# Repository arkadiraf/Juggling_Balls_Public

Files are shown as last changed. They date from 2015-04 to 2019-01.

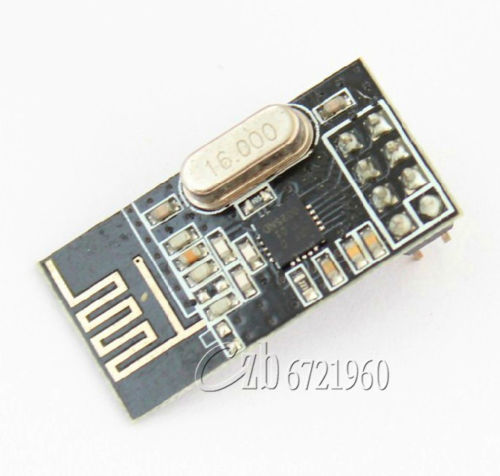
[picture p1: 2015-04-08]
Images/NRF24.JPG

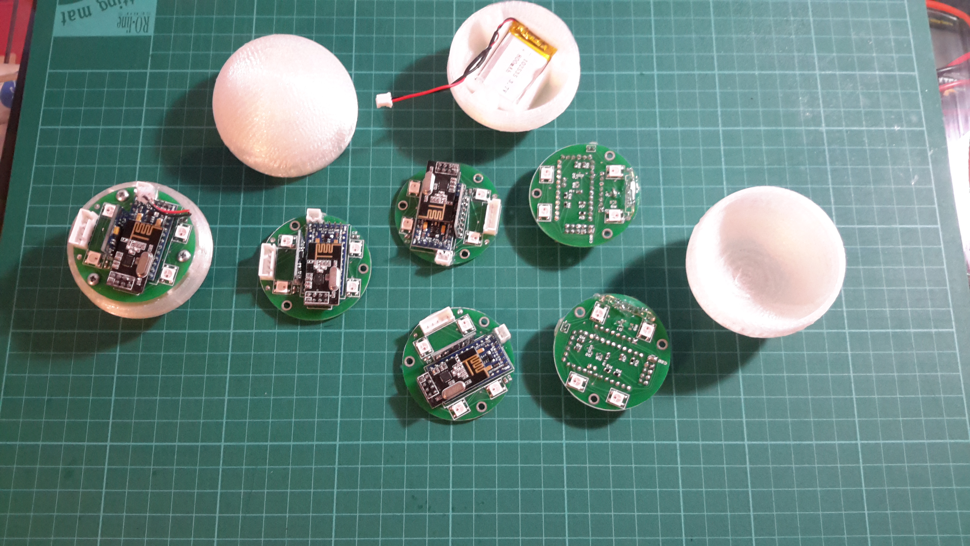
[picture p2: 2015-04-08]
Images/20150408_191757.jpg

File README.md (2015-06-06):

# Juggling_Balls_Public
Smart Juggling Balls is a project of mine which consists of 3 basic modules: 
arduino pro mini (compatible) MPU 6050 and nrf24
and a bunch of LEDS of course :)
The files I publish include the PCB manufacturing Gerber files
STL files for the casing (ment for 3d printing)
and some code I wrote.
The idea is to have colorful and happy juggling balls which can change lightning based on the sensor readings 
and remote maniputations communicating via nrf24.

<br /><span xmlns:dct="http://purl.org/dc/terms/" property="dct:title">Juggling_Balls</span> is licensed under a <a rel="license" href="http://creativecommons.org/licenses/by-nc-sa/4.0/">Creative Commons Attribution-NonCommercial-ShareAlike 4.0 International License</a>.

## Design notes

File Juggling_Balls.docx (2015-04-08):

Smart Juggling Balls: https://youtu.be/MuF92wXwjuk

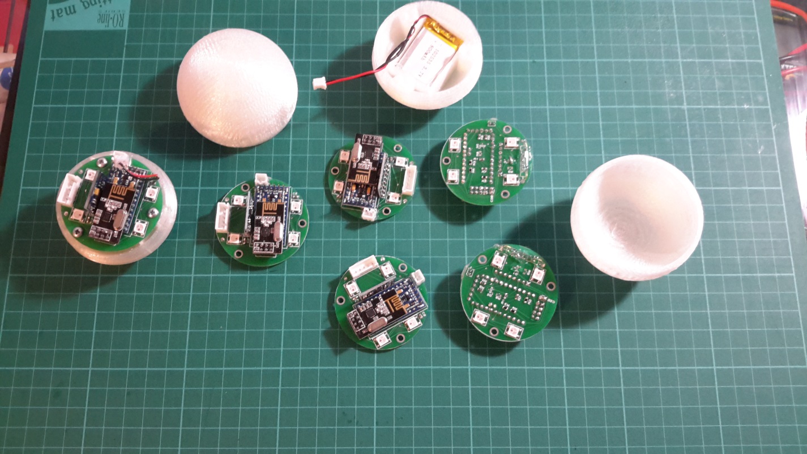
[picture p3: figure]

This is my version for smart juggling balls, the files I share include PCB Circuit manufacture files (Gerber)

STL models for the casing, and codes (currently Test code).

It is possible to assemble the juggling balls using a prototype PCB such as: https://www.sparkfun.com/products/8810 my first iterations were based on the same prototype board and later the PCB was design based on the physical dimensions of the board.

The circuit itself can be ordered from SeeeStudio http://www.seeedstudio.com/service/index.php?r=pcb

Just upload the Attached zip in Circuit→JB_Gerber.zip and order a standard 2 layer pcb. (Schematics are available in Circuit→Juggling_Balls.PDF

STL files for the casing are available in STL→Juggling_Maker_Faire

There are 2 versions one is a bit thicker.

All parts and links are available in Juggling_Balls_Bom.xlsx

Some notes on assembling:

Currently the power circuit (Transistor and mosfet) weren`t tested out,I use a wire to short the mosfet and use the connected pin (D8) as a magnet detector through the reed switch.

In one of the batches the holes for the arduino board came a bit tight so I was required to drill wider and then solder the pins for the arduino model from both sides of the pcb.

The Nrf model pins are needed to be cut a bit and the plastics removed so the NRF model will sit flat on the 2x4 header.

The circuit is design for the arduino compatible models available on ebay, such that the pinout for the FTDI is as in the image: (alternatively it is possible to use a different arduino version without soldering the FTDI headers to the pcb board, in that case the 5 pin connector will not be connected to the board DTR).

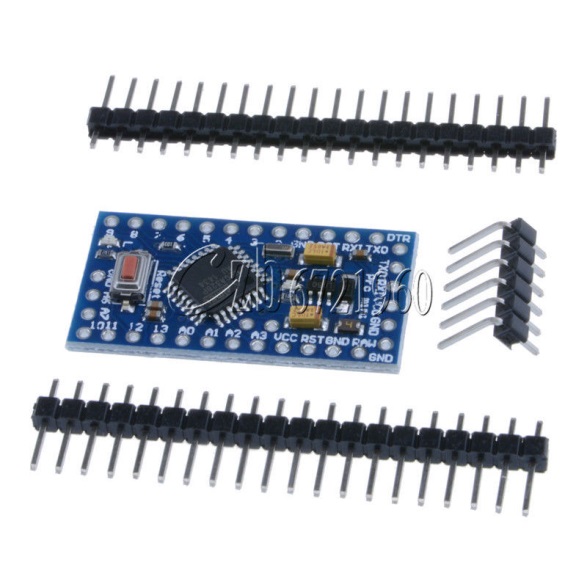
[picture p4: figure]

The direction of the SMD RGB LEDS such that the ‘cut’ corner of the LED first in the small Square drawn on the PCB.

All Resistors and capacitors aren`t Solid science, feel free to make variations, I myself solder a 1 uF capacitor instead the 47 uF and use 10kOhm resistors instead the 47kOhm

Note the correct direction for the Pin headers

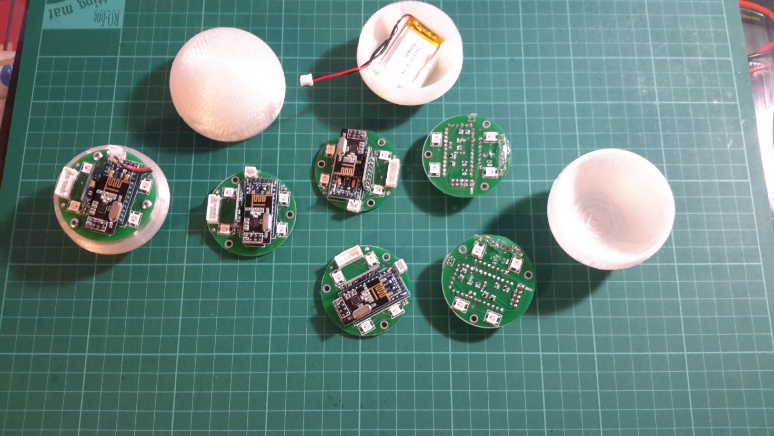
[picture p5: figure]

Enjoy.

Thanks to Eugene: http://techno-mind.ru/ for helping with the initial PCB design for manufacturing.

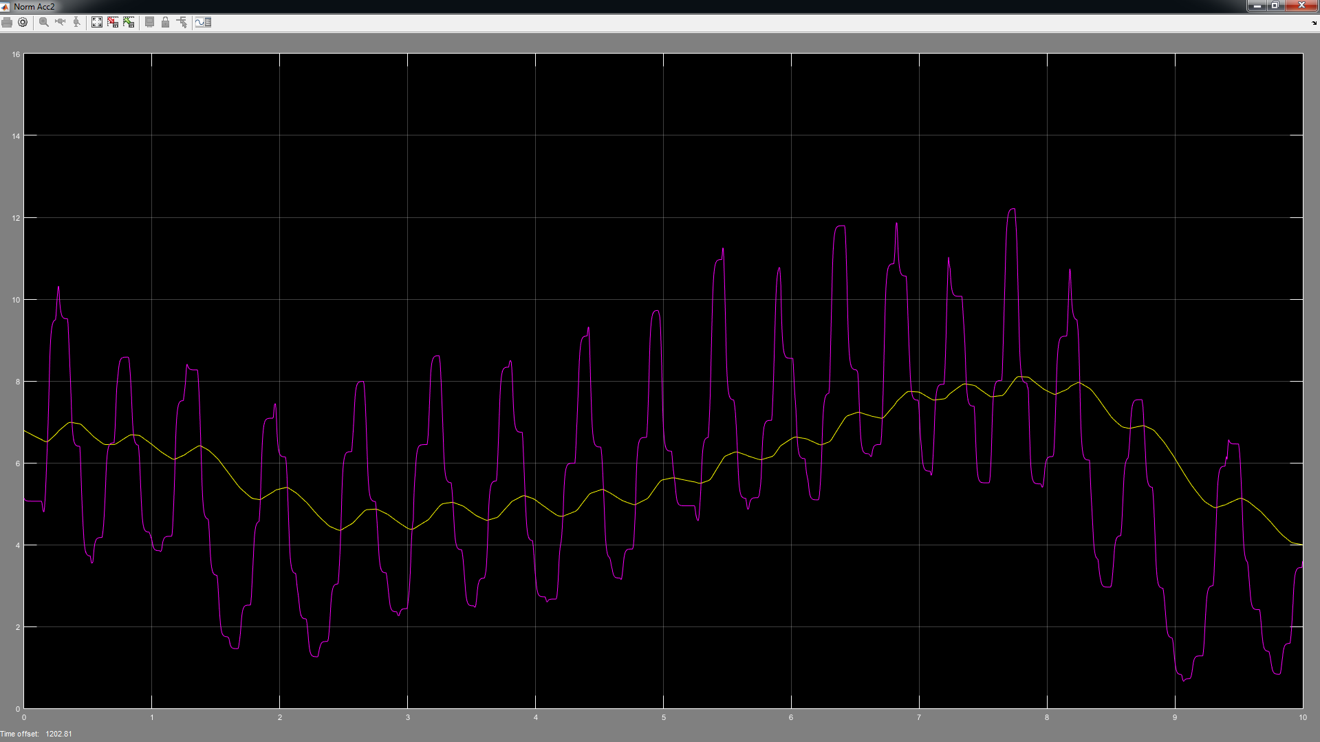
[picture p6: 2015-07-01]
Images/Filter_Acceleration.png

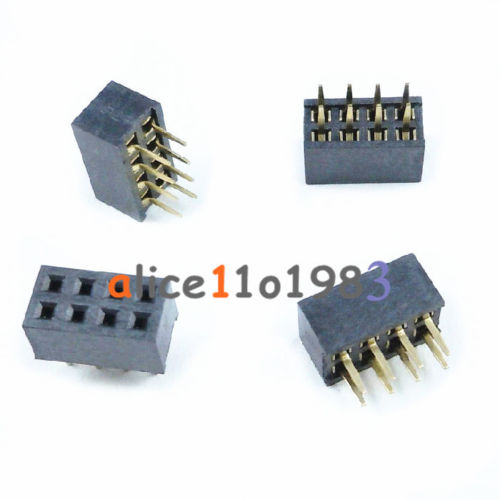
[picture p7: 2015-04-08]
Images/Header.JPG

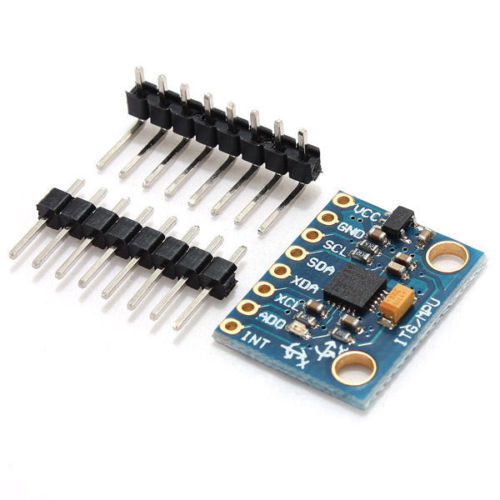
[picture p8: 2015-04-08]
Images/MPU6050.JPG

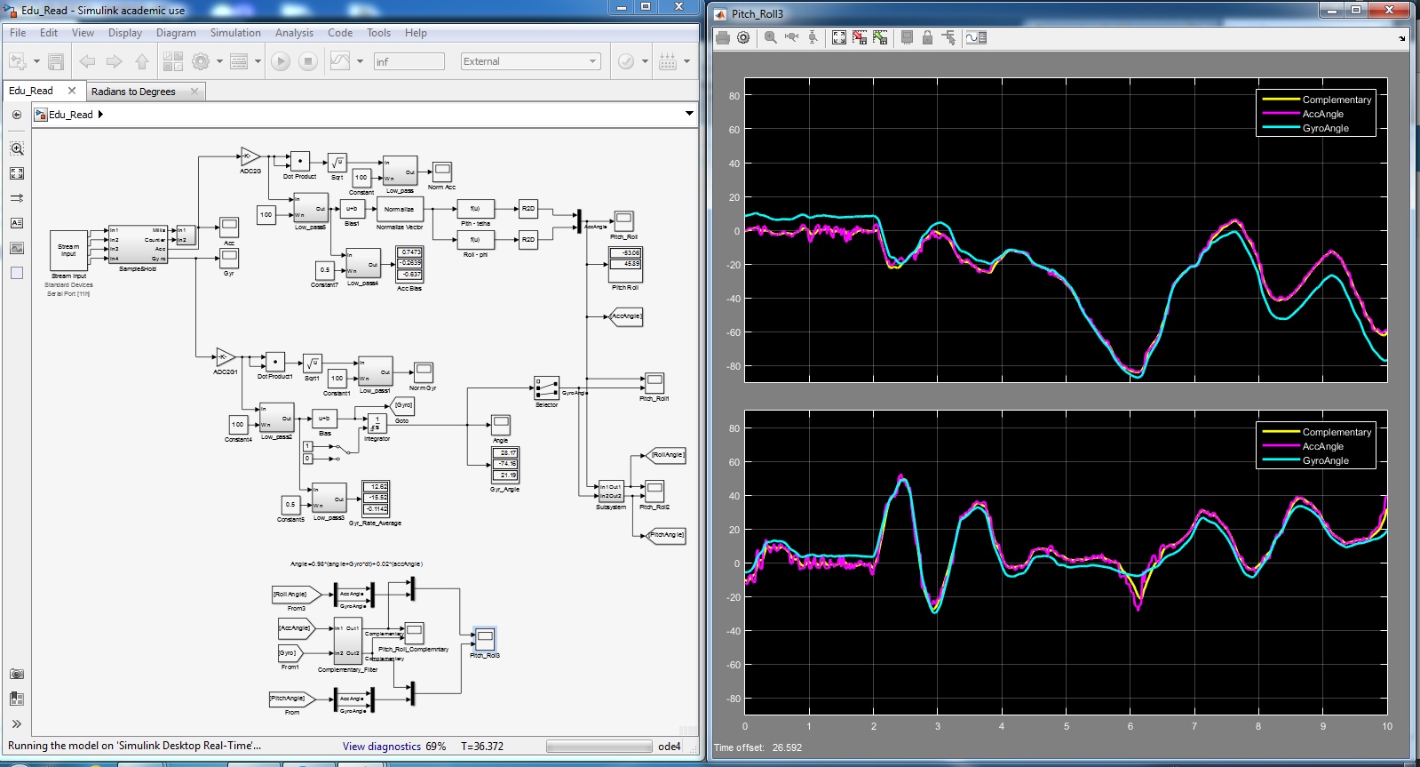
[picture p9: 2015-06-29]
Images/Edu_Simulink_Example.jpg

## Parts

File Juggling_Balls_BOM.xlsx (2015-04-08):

 | Juggling Balls Parts
Item |  | Link
1 circuit PCB or Prototype round PCB: |  | https://www.sparkfun.com/products/8810
Casing (3d Printed) |  | STL Files
Arduino Compatible pro mini |  | http://www.ebay.com/itm/131091305008?_trksid=p2060778.m2749.l2649&ssPageName=STRK%3AMEBIDX%3AIT
MPU 6050 |  | http://www.ebay.com/itm/161267559751?_trksid=p2060778.m2749.l2649&ssPageName=STRK%3AMEBIDX%3AIT
NRF24L01 |  | http://www.ebay.com/itm/140729183185?_trksid=p2060778.m2749.l2649&ssPageName=STRK%3AMEBIDX%3AIT
ReedSwitch |  | http://www.ebay.com/itm/161267559751?_trksid=p2060778.m2749.l2649&ssPageName=STRK%3AMEBIDX%3AIT
Li-Ion Battery |  | http://www.aliexpress.com/snapshot/6526903112.html?orderId=66147013510053
SMD Parts: | SeeedStudio | http://www.seeedstudio.com/depot/OPLopen-parts-library-catalog-c-136_138/?ref=side
WS2812b LED | SKU: 800052001 | http://www.seeedstudio.com/depot/WS2812B-RGB-LED-with-Integrated-Driver-Chip-10-PCs-pack-p-1675.html
Mosfet |  | SMD MOSFET P-CH -8V -4.1A(0440210P1)
Transistor |  | SMD Transistors NPN 25V-500mA(0400000P1)
Resistors |  | SMD RES 10K-5%-1/8W(301010304)
 |  | SMD RES 47K-1%-1/8W(301010388)
 |  | SMD RES 220R-5%-1/8W(301010315
 |  | SMD RES 1K-5%-1/8W(301010311)
Capacitors |  | SMD CAP Ceramic 100nF-50V-10%-X7R;(302010165)
 |  | SMD CAP Ceramic 1uF-25V-10%-X7R(0100440P1)
Connectors |  | DIP JST 2P-2.0(320110049)
DIP JST 5P 2.5 |  | http://www.ebay.com/itm/10-kits-XH2-54mm-5pin-JST-Connector-plug-Male-Female-Crimps-DIP-5P-/331376224432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
DIP 8P 2x4 Female header 2.54 |  | http://www.ebay.com/itm/10PCS-2x4-Pin-8P-2-54mm-Double-Row-Female-Straight-Header-Pitch-Socket-Pin-Strip-/310727244114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
Alternative sensor:
MPU 9150 |  | http://www.ebay.com/itm/161096342893?_trksid=p2060778.m2749.l2649&ssPageName=STRK%3AMEBIDX%3AIT

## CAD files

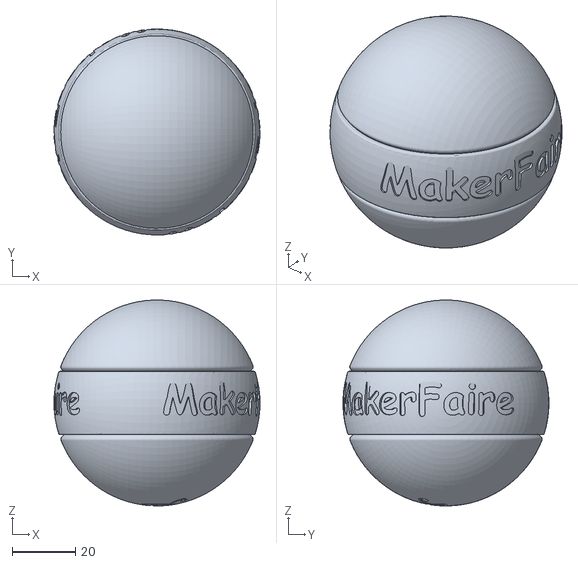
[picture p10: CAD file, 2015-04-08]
STL/Juggling_MakerFaire.STL
65.0 x 65.0 x 64.9

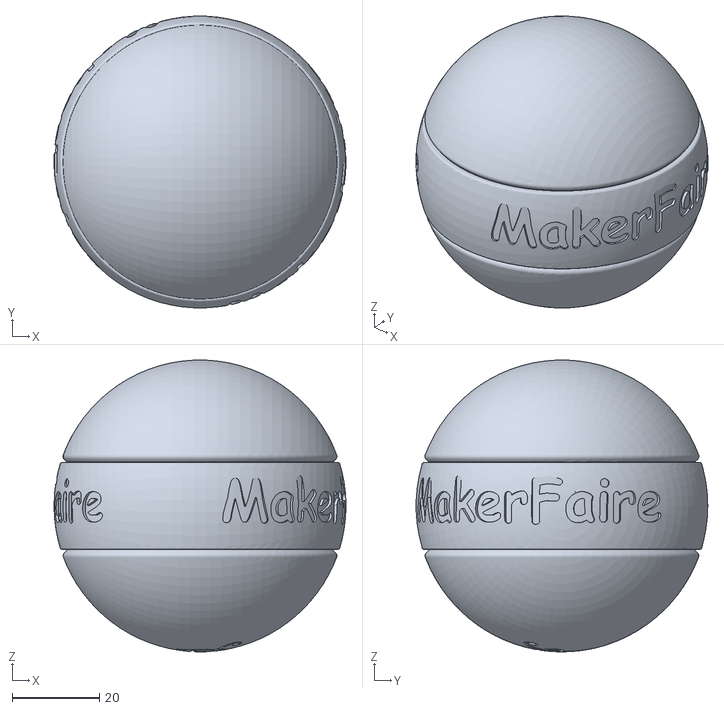
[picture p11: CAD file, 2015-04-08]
STL/Juggling_2_MakerFaire.STL
67.0 x 66.9 x 66.9

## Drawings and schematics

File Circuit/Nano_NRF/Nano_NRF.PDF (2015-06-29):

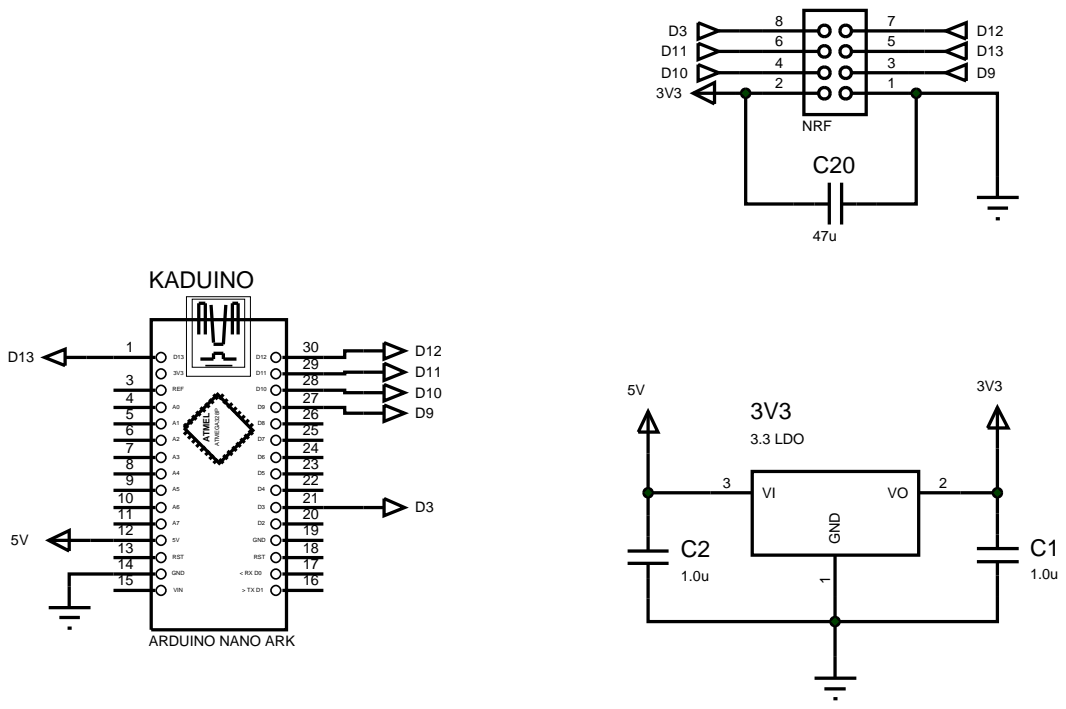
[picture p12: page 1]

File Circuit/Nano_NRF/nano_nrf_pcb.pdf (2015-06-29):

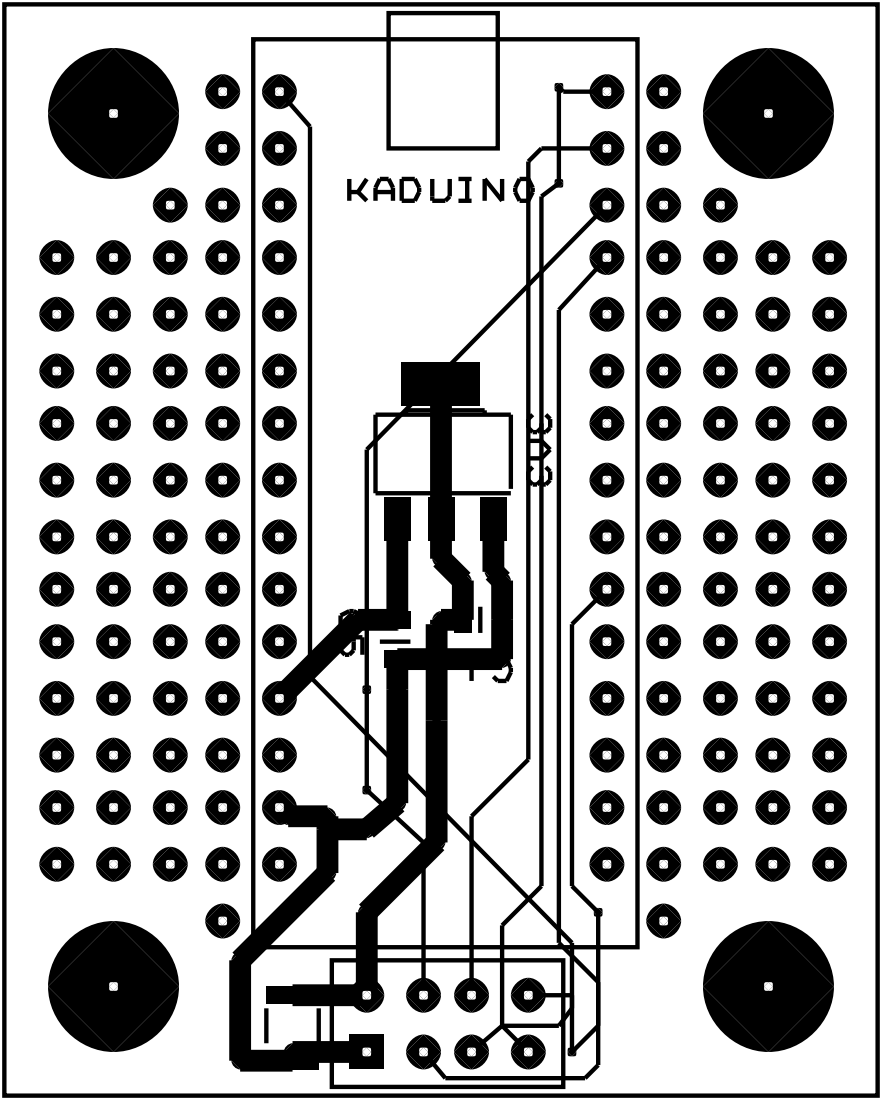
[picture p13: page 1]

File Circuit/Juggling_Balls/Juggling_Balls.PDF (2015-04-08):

R7
C1

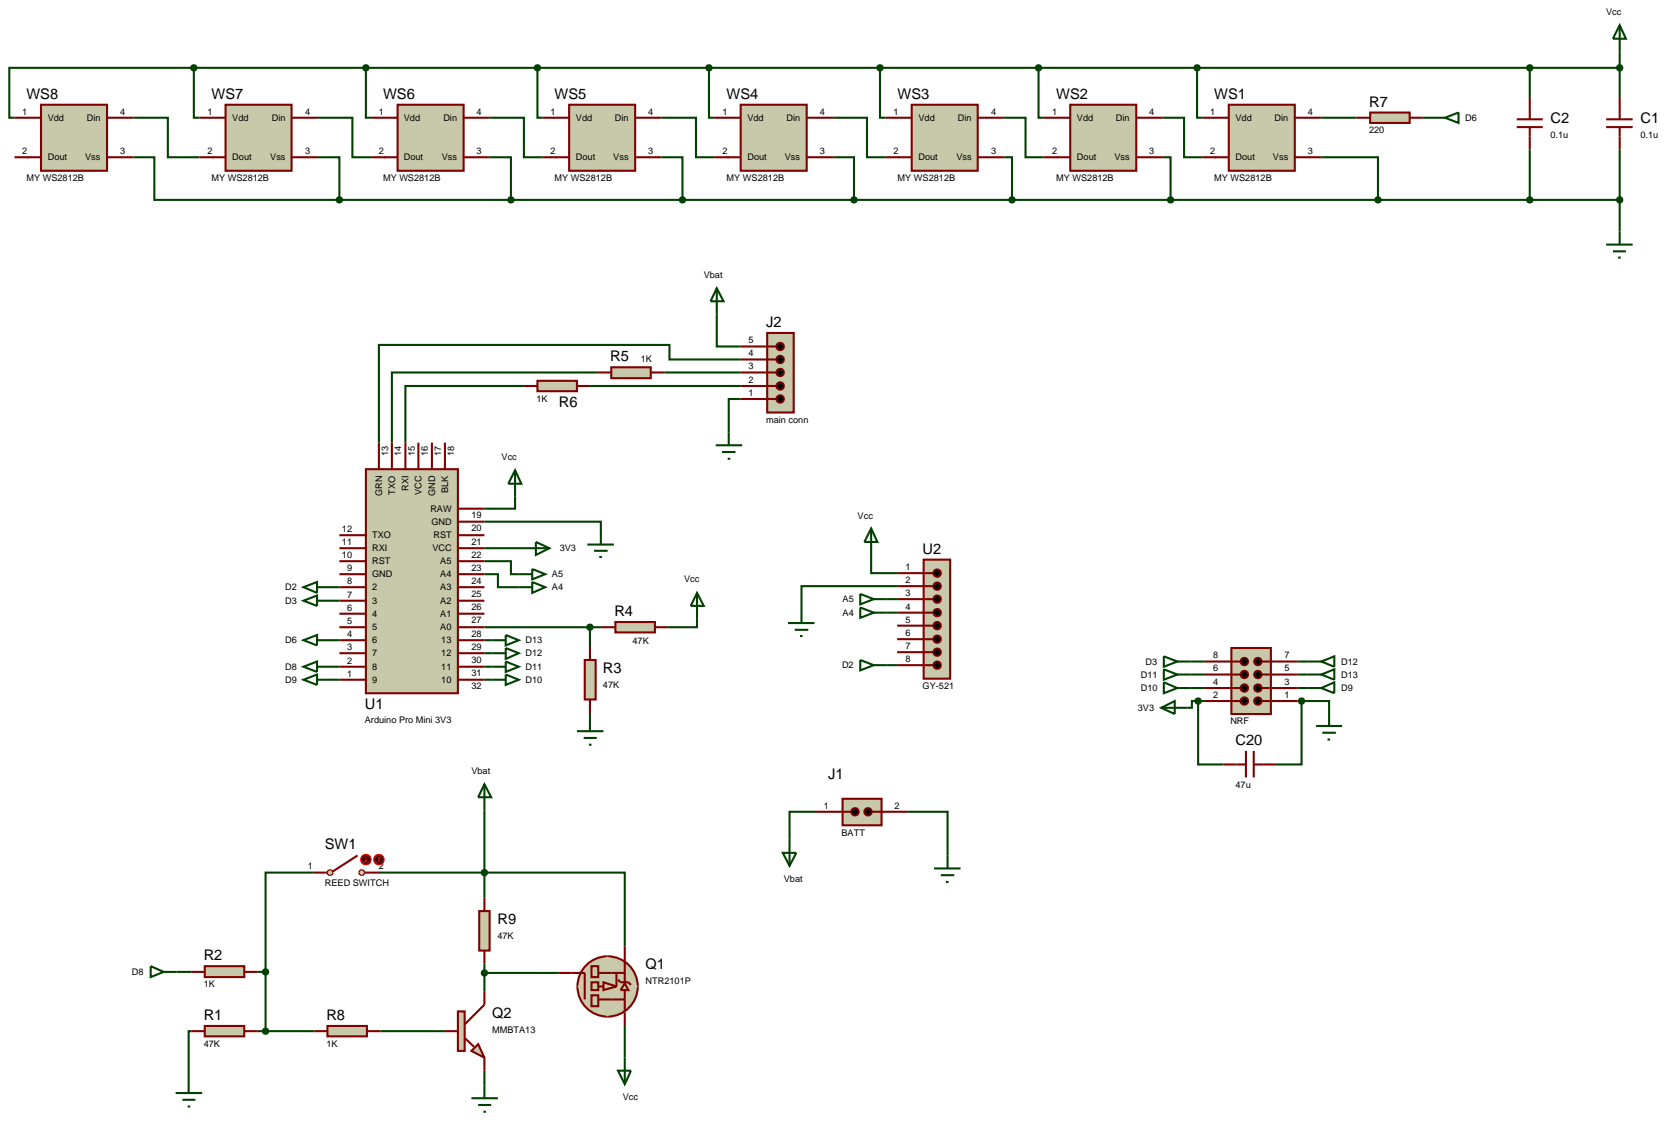
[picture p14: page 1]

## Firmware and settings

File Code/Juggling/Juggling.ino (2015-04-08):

// Juggling balls Test code

/* Pinout:
    Arduino:
    A5 (SCL)-->SCL
    A4 (SDA)-->SDA
    D2-->INT DRDYG
    
    D8-->Reed Switch
    
    D6-->NeoPIxel DataIn
    
    A0-->Vraw/2
    
    D9-->CE NRF
    D10-->CSN NRF
    D13 (SCK)-->SCK NRF
    D11 (MOSI)-->MOSI NRF
    D12 (MISO)-->MISO NRF
    D3-->IRQ
    
    connector:
    Vcc--> baterry Vcc
    Dtr --> directly
    Tx --> through 1k // in order to protect from shorts
    Rx --> through 1k
    Grnd --> battery GRN
*/

///////////////
// libraries //
///////////////
#include <math.h>
#include <SPI.h>
#include "nRF24L01.h"
#include "RF24.h"
#include <Adafruit_NeoPixel.h>
#include "I2Cdev.h"
#include "MPU6050.h"
#include "Wire.h"

///////////////
// Variables //
///////////////

#define rad2deg 57.295

///////////////
// MPU 6050 //
///////////////

MPU6050 accelgyro;

#define MPUREADDELAY 100
// Single radio pipe address for the 2 nodes to communicate.
unsigned long MpuMillisStamp=0;

const byte INT_MPU_PIN = 2; // INT DRDYG

int16_t ax, ay, az;
int16_t gx, gy, gz;

double AcclValue[3]={0,0,0}; //in G values
double GyroValue[3]={0,0,0}; //in Degrees per second

#define SAMPLE2GACC 2048.0   // +/-16g full scale, 16 bit resolution--> 2^16/32=2048
#define SAMPLE2AGYRO 16.384  // +/-2000 Deg/Sec, 16 but tesolution--> 2^16/4000=16.384
	
////////////////////////////
// communication variable //
////////////////////////////
#define CommunicationDelay 500
// Single radio pipe address for the 2 nodes to communicate.
unsigned long CommunicationMillisStamp=0;

// Set up nRF24L01 radio on SPI bus plus pins 9 & 10
RF24 radio(9,10);
// Radio pipe addresses for the 2 nodes to communicate.
const uint64_t pipes[2] = { 0xF0F0F0F0E1LL, 0xF0F0F0F0D2LL };



/////////////
// Battery //
/////////////
double Vbaterry=3.7;
#define VBATTERY_PIN A0
#define ADC2VBAT 155.0 // Convert ADC reading to voltage, VBatt/2=Vref/ADC_Res
#define BATTERYMINIMUM 3.3 // minimum allowed battery voltage
byte BatteryStatus=1; // variable to indicate battery status,0- empty, 1-full
#define BatterySampleDelay 1000 // sample period of the battery voltage
unsigned long VbatSampleMillis=0; // variable to hold millis counter

////////////////
// Neo Pixels //
////////////////
#define NEOPIXELS 8
#define NEODATAPIN 6
// neo Pixel initialize
Adafruit_NeoPixel strip = Adafruit_NeoPixel(NEOPIXELS, NEODATAPIN, NEO_GRB + NEO_KHZ800);


/////////////////////
// Juggling Status //
/////////////////////

double AcclNorm=0;

#define REEDSWITCHPIN 8
int MagStatus=0;
// define colors array
// [White,Red,Lime,Blue,Yellow,Cyan,Magenta,Maroon,Olive,Green,Purple,Teal,Navy]  from http://www.rapidtables.com/web/color/RGB_Color.htm
#define NUMOFCOLORS 13
long ColorsArr[NUMOFCOLORS]={0xFFFFFF,0xFF0000,0x00FF00,0x0000FF,0xFFFF00,0x00FFFF,0xFF00FF,0x800000,0x808000,0x008000,0x800080,0x008080,0x000080};
byte CurrColorNum=0;
uint32_t Color=0x000000;
#define ColorBlack 0x000000

// Status based on accelerometer
// 0- free fall, 1- 1G, 2- bump or anything else
byte AcclStatusArr[3]={1,1,1};

// Mode based on Magnetometer
// 0- No Magnet, 1- Magnet,
byte MagStatusArr[3]={1,1,1};
// set pixel state
// 0- do nothing, 1- change color, 2- 1G be green
byte PixelState=0;
#define PixelsNumStates 3
// 0- off, 1- all colors the same, 2- chasing one color, 3-chasing 2 colors,
byte PixelsMode=0;
#define PixelsNumModes 4
// variable to store pixel referance for theater chasing mode
int theaterChasePixel=0;

unsigned long theaterChaseMillis=0; // timer counter
#define theaterChaseDelay 100


///////////////
// SETUP	 //
///////////////
void setup(){
      // join I2C bus (I2Cdev library doesn't do this automatically)
    Wire.begin();
    // initialize serial communication
    Serial.begin(57600);
  // neo Pixel initialize
  strip.begin();
  strip.show(); // Initialize all pixels to 'off'
  
  // Nrf initialize
  radio.begin();
  radio.setRetries(15,15);
  radio.openWritingPipe(pipes[0]);
  radio.openReadingPipe(1,pipes[1]);
  
  radio.startListening();
  
  //MPU6050 Settings
  // initialize device
    accelgyro.initialize();

    // verify connection
    Serial.println(accelgyro.testConnection() ? "MPU6050 connection successful" : "MPU6050 connection failed");

    // change accel/gyro scale values
    // set accelerometer to 16G and gyro to 2000 deg/sec
    accelgyro.setFullScaleAccelRange(MPU6050_ACCEL_FS_16);
    accelgyro.setFullScaleGyroRange(MPU6050_GYRO_FS_2000);
  
  // set battery pin as input and read voltage
  pinMode(VBATTERY_PIN, INPUT);
  Vbaterry=((double)analogRead(VBATTERY_PIN))/ADC2VBAT;
  
  // Set pin modes
  pinMode(REEDSWITCHPIN, INPUT);
  // interrupt pins
  pinMode(2, INPUT);
  pinMode(3, INPUT);

}

///////////////
// MAIN LOOP //
///////////////
void loop(){
	
	// update battery voltage
	if ((millis()-VbatSampleMillis)>BatterySampleDelay){
		VbatSampleMillis=millis();
		Vbaterry=((double)analogRead(VBATTERY_PIN))/ADC2VBAT;
		if (Vbaterry>(BATTERYMINIMUM+0.1)){ //add 0.1 in order to remove turning on and off when battery close to value.
			BatteryStatus=1;
		}else if (Vbaterry<BATTERYMINIMUM){
			BatteryStatus=0;
		}
		Serial.println(Vbaterry);
	}
	 // accelerometer interrupt ready
	 if ((millis()-MpuMillisStamp)>MPUREADDELAY){
                MpuMillisStamp=millis();
                // read raw accel/gyro measurements from device
                accelgyro.getMotion6(&ax, &ay, &az, &gx, &gy, &gz);
                AcclValue[0]=((double)ax)/SAMPLE2GACC;
                AcclValue[1]=((double)ay)/SAMPLE2GACC;
                AcclValue[2]=((double)az)/SAMPLE2GACC;
                
		AcclNorm=AcclValue[0]*AcclValue[0]+AcclValue[1]*AcclValue[1]+AcclValue[2]*AcclValue[2];
		AcclNorm=sqrt(AcclNorm);
		// update accelerometer status
		for (int ii=2; ii>0; ii--){
			AcclStatusArr[ii]=AcclStatusArr[ii-1];
		}
		if (AcclNorm<0.4){
			AcclStatusArr[0]=0;	// free fall
		} else if(AcclNorm<1.5){
			AcclStatusArr[0]=1;	// Gravity
		}else{
			AcclStatusArr[0]=2;	// bump or anything else
		}
		
		// change color based on start of free fall
		if (AcclStatusArr[0]==0){
			if (AcclStatusArr[1]==0){
				if (AcclStatusArr[2]!=0){
					PixelState=1; //change color
				}
			}
		}
		
		// One color when in hand
		if (AcclStatusArr[0]==1){
			if (AcclStatusArr[1]==1){
				if (AcclStatusArr[2]==1){
					PixelState=2; //Set color
				}
			}
		}
		
		//Serial.print("A: ");
		//// millis
		//Serial.print(millis());
		//Serial.print(", ");
		//// Using the calcAccel helper function, we can get the
		//// accelerometer readings in g's.
		//Serial.print(AcclValue[0],4);
		//Serial.print(", ");
		//Serial.print(AcclValue[1],4);
		//Serial.print(", ");
		//Serial.println(AcclValue[2],4);
		
		//Serial.println(AcclStatus);


            	// update ReedSwitch status
                MagStatus=digitalRead(REEDSWITCHPIN);
            
		for (int ii=2; ii>0; ii--){
			MagStatusArr[ii]=MagStatusArr[ii-1];
		}
                MagStatusArr[0]=MagStatus;
		
		if ((MagStatusArr[0])&&(MagStatusArr[1])&&(!MagStatusArr[2])){ // magnet detected, switch between modes
			PixelsMode++;
			PixelsMode=PixelsMode%PixelsNumModes;
		}

	
	}
 
  
  
  
  
unsigned long TimeMillis=millis();
  if (((TimeMillis-CommunicationMillisStamp)>CommunicationDelay)||(CommunicationMillisStamp>TimeMillis)){
    CommunicationMillisStamp=TimeMillis;
  
    radio.stopListening();  
    int ok = radio.write( &Vbaterry, sizeof(double) );
    if(ok){Serial.println("ok");}else{Serial.println("not ok");}
    Serial.println(Vbaterry);
    radio.startListening();    
    
  }

	// neopixels:
	if((BatteryStatus)&&(PixelsMode)){ //lets play
		
		if (PixelState==1){ //change color
			PixelState=0;
			CurrColorNum++;
			CurrColorNum=CurrColorNum%NUMOFCOLORS;
			Color=ColorsArr[CurrColorNum];
			if (PixelsMode==1){
				colorWipe(Color);
			}
		}
		
		if (PixelState==2){ //be green when in hand
			PixelState=0;
			Color=0x00FF00;
			if (PixelsMode==1){
				colorWipe(Color);
			}
		}
		
		if (PixelsMode==2){
			if ((millis()-theaterChaseMillis)>theaterChaseDelay){
			theaterChaseMillis=millis();
			theaterChase(Color);
			}
		}
		if (PixelsMode==3){
			if ((millis()-theaterChaseMillis)>theaterChaseDelay){
				theaterChaseMillis=millis();
				uint32_t c1=ColorsArr[CurrColorNum] ;
				uint32_t c2=ColorsArr[((CurrColorNum+1)%NUMOFCOLORS)];
				uint32_t c3=ColorsArr[((CurrColorNum+2)%NUMOFCOLORS)];
				theaterChaseMultiColor(c1,c2,c3);
			}
		}
		
		
	}else{		
		//turn pixels off except one
		for(uint16_t i=0; i<strip.numPixels(); i++) {
			strip.setPixelColor(i, ColorBlack);
		}
		strip.setPixelColor(0,0xFF0000);
		strip.show();
	}			

}// end main



/////////////////////////
// Neo Pixels Functions//
/////////////////////////

// Wipe color Color
void colorWipe(uint32_t c) {
	for(uint16_t i=0; i<strip.numPixels(); i++) {
		strip.setPixelColor(i, c);
	}
	strip.show();
}

//Theatre-style crawling lights.
void theaterChase(uint32_t c) {
	theaterChasePixel++;
	theaterChasePixel=theaterChasePixel%3;
	// set all pixels off
	for (int i=0; i<strip.numPixels();i++){
		strip.setPixelColor(i,ColorBlack);
	}
	//turn every third pixel on starting at the theaterChasePixel
	for (int i=theaterChasePixel; i<strip.numPixels();i=i+3){
		strip.setPixelColor(i, c);    
	}
	strip.show();
}

//Theatre-style crawling lights multi color.
void theaterChaseMultiColor(uint32_t c1, uint32_t c2, uint32_t c3) {
	theaterChasePixel++;
	theaterChasePixel=theaterChasePixel%3;
	// color every third pixel	
	for (int i=0; i<strip.numPixels();i=i+3){ 
		strip.setPixelColor((i+theaterChasePixel)%strip.numPixels(),c1);
	}
	// color every third pixel
	for (int i=0; i<strip.numPixels();i=i+3){
		strip.setPixelColor((i+theaterChasePixel+1)%strip.numPixels(),c2);
	}
	// color every third pixel
	for (int i=0; i<strip.numPixels();i=i+3){
		strip.setPixelColor((i+theaterChasePixel+2)%strip.numPixels(),c3);
	}
	strip.show();
}




// calculate heading
float calcHeading(float hx, float hy)
{
	if (hy > 0)
	{
		return 90 - (atan(hx / hy) * 180 / PI);
	}
	else if (hy < 0)
	{
		return 270 - (atan(hx / hy) * 180 / PI);
	}
	else // hy = 0
	{
		if (hx < 0) return 180;
		else return 0;
	}
}

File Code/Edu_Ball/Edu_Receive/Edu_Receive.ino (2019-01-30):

// Edu_Ball 31/05/2015 11:37

/* Pinout:
    Arduino Nano 5V: 
    D9-->CE NRF
    D10-->CSN NRF
    D13 (SCK)-->SCK NRF
    D11 (MOSI)-->MOSI NRF
    D12 (MISO)-->MISO NRF
    D3-->IRQ
*/
///////////////
// libraries //
///////////////
#include <SPI.h>
#include "nRF24L01.h"
#include "RF24.h"

///////////////
// Variables //
///////////////

// declrae Message in unione format 
#define MSGLENGHT 18
union Message_Type
{
  uint8_t  MBytes[MSGLENGHT]; //Blue Green Red
    struct MSG_Type
  {
    uint32_t Millis;
    uint16_t Counter;
    int16_t Acc[3];
    int16_t Gyr[3];  
  }MSG;
}Message;

#define SAMPLE2GACC 2048.0   // +/-16g full scale, 16 bit resolution--> 2^16/32=2048
#define SAMPLE2AGYRO 16.384  // +/-2000 Deg/Sec, 16 but tesolution--> 2^16/4000=16.384
	
////////////////////////////
// communication variable //
////////////////////////////

// Set up nRF24L01 radio on SPI bus plus pins 9 & 10
RF24 radio(9,10);
// Radio pipe addresses for the 2 nodes to communicate.
//const uint64_t pipes[2] = { 0xF0F0F0F0E1LL, 0xF0F0F0F0D2LL };
const uint64_t Rxpipes =0xB3F3F3b3b7LL;
const uint64_t Txpipes =0xA3F3F3bA3c3LL;

int msgSkip = 0;





///////////////
// SETUP	 //
///////////////
void setup(){
    // initialize serial communication
    Serial.begin(115200);
  
  // Nrf initialize
  radio.begin();
  radio.setChannel(52);
  radio.setPALevel(RF24_PA_HIGH);
  radio.setDataRate(RF24_1MBPS);
  radio.setPayloadSize(MSGLENGHT);
  radio.setRetries(0,0);
  radio.setAutoAck(false);
  radio.openWritingPipe(Txpipes);
  radio.openReadingPipe(1,Rxpipes);
  radio.startListening();

  // interrupt pins
  pinMode(3, INPUT);
  
  //initialize communication struct:
  Message.MSG.Millis=0;
  Message.MSG.Counter=0;
  
}

///////////////
// MAIN LOOP //
///////////////
void loop(){
	 // receive messega
	 if (radio.available()){
    radio.read( &Message.MBytes, MSGLENGHT );
    msgSkip++;        
    if (msgSkip%1 == 0){
//            Serial.print("mill: ");
//            Serial.print(Message.MSG.Millis);
//            Serial.print(" Cnt: ");
//            Serial.print(Message.MSG.Counter);
//            Serial.print(" acc: ");
//            Serial.print(Message.MSG.Acc[0]);
//            Serial.print(", ");
//            Serial.print(Message.MSG.Acc[1]);
//            Serial.print(", ");
//            Serial.print(Message.MSG.Acc[2]);
//            Serial.print(", ");
//            Serial.print(Message.MSG.Gyr[0]);
//            Serial.print(", ");
//            Serial.print(Message.MSG.Gyr[1]);
//            Serial.print(", ");
//            Serial.println(Message.MSG.Gyr[2]);
            
            // send to matlab/simulink:
            Serial.print("MSG:");
            Serial.print(Message.MSG.Millis);
            Serial.print(",");
            Serial.print(Message.MSG.Counter);
            Serial.print(",");
            Serial.print(Message.MSG.Acc[0]);
            Serial.print(",");
            Serial.print(Message.MSG.Acc[1]);
            Serial.print(",");
            Serial.print(Message.MSG.Acc[2]);
            Serial.print(",");
            Serial.print(Message.MSG.Gyr[0]);
            Serial.print(",");
            Serial.print(Message.MSG.Gyr[1]);
            Serial.print(",");
            Serial.println(Message.MSG.Gyr[2]);
    }    
   }         
}// end main

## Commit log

2015-04-08 Juggling Balls initial files
    [Juggling_2_MakerFaire.STL, Juggling_Balls_BOM.xlsx, Juggling_MakerFaire.STL]
2015-04-08 Update 08/04/2015
    [Juggling_Balls_BOM.xlsx]
2015-07-01 EduBall Simulink update
    added some print screens of effects
2019-01-30 added i2c dev
